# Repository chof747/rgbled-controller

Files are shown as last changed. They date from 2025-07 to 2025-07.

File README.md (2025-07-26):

# RGB-Led Controller

## Idea

This is a WiFi enabled RGB LED controller with the following features:

- Power in from the main 5V power source and stepping down to 3v3 for the MCU
- Pass through of the power to the led strips
- ESP8266 MCU with boot strap, reset and flash logic
- Programming header for auto-reset and flash enabled programming
- Boot and reset button
- IDC header breaking out I2C, 3v3, GND, FLASH (as additional GPIO) and RESET pin
- LED data out (at level of 5V via level shifter)
- Breakout of not used GPIOs 12-14 plus GND
- Wake up circuit prepared with a solder bridge

The WiFi controller is also ammended by a peripheral board that contains:

- 5 Light and 1 Mod Button
- A Temperature and Humidity Sensor
- An MCP23017 for IO expansion
- A breakout for the unused pins of the IO Expander
- An IDC connection with the same pin-out as the IDC connection of the Controller

## Components

- ESP8266 as an ESP12-F module
- ME6211C33M5G-N (voltage regulator)
- 2n7002 MOSFET (level shifting)
- UMH3N (auto reset circuit)
- Screw terminals for Power in and LED Power + Control out
- IDC 2x3 for I2C breakout
- Std Pin headers for programming header and unused pins breakout
- 0.5A Fuse
- SMD Push buttons
- MCP23017 (I2C)
- SHT40x (temperature controller)
- BAT54C (OR Gate type diodes)

## Revision History

**V1.0** - send to production 26.07.2025

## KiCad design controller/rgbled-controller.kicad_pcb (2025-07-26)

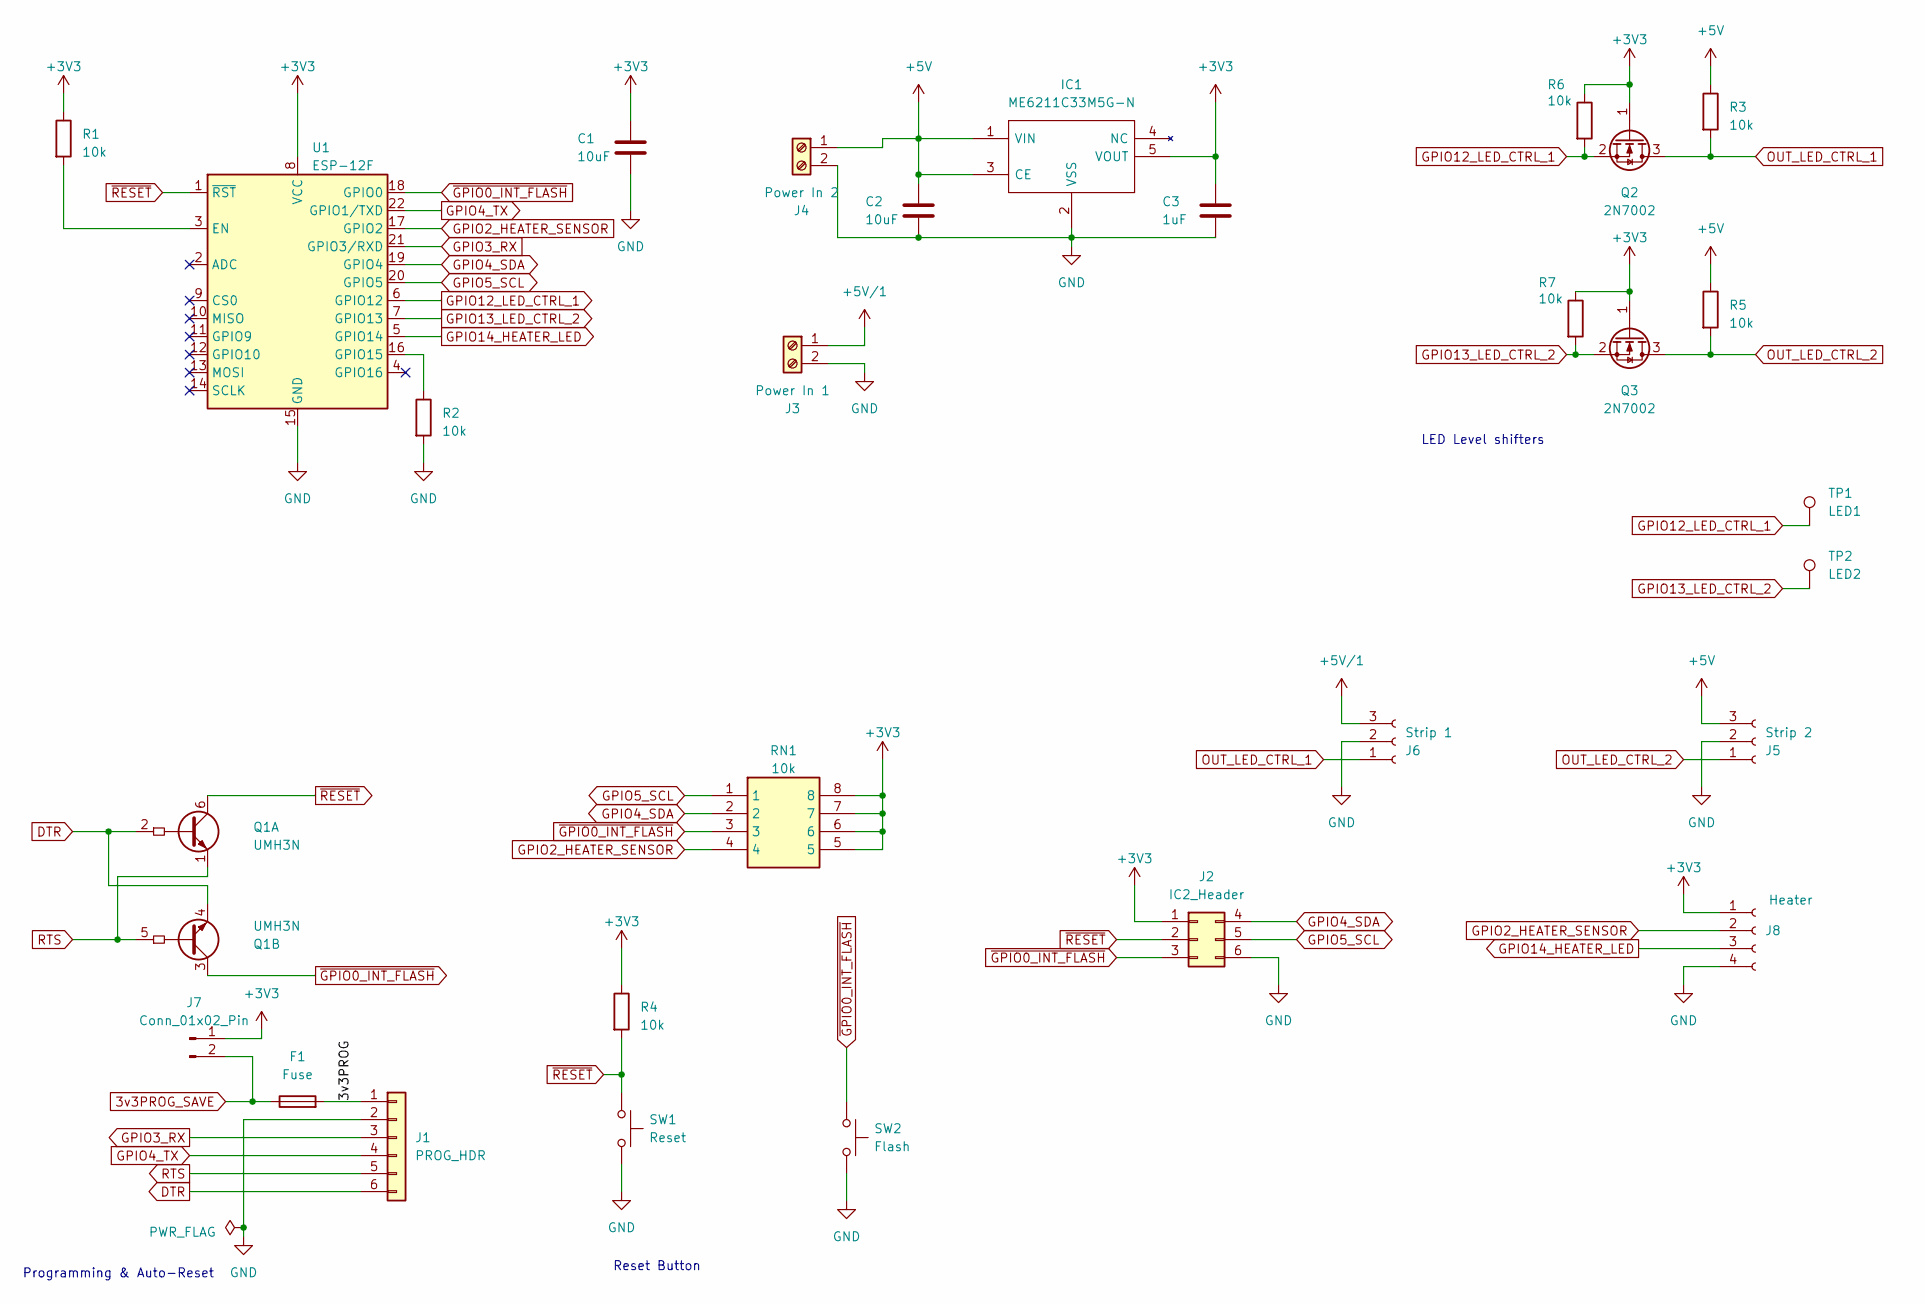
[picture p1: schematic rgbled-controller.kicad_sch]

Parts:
C1, C2: 10uF; C_0603_1608Metric_Pad1.08x0.95mm_HandSolder
C3: 1uF; C_0603_1608Metric_Pad1.08x0.95mm_HandSolder
F1: Fuse; Fuse_0805_2012Metric_Pad1.15x1.40mm_HandSolder
IC1: ME6211C33M5G-N; SOT95P270X145-5N; Manufacturer_Part_Number ME6211C33M5G-N
J1: PROG_HDR; PinHeader_1x06_P2.54mm_Vertical
J2: IC2_Header; HDR-TH_6P-P2.54-V-F-R2-C3-S2.54-4
J3: Power In 1; TerminalBlock_bornier-2_P5.08mm
J4: Power In 2; TerminalBlock_bornier-2_P5.08mm
J5: Strip 2; TerminalBlock_bornier-3_P5.08mm
J6: Strip 1; TerminalBlock_bornier-3_P5.08mm
J7: Conn_01x02_Pin; PinHeader_1x02_P2.54mm_Vertical
J8: Heater; CONN-TH_4P-P2.54_KF128-2.54-4P
Q1: UMH3N; SOT-363_SC-70-6
Q2, Q3: 2N7002; SOT-23
R1, R2, R3, R4, R5, R6, R7: 10k; R_0603_1608Metric_Pad0.98x0.95mm_HandSolder
RN1: 10k; YC164JR07220RL; Manufacturer_Part_Number YC164-FR-0710KL; Mouser Part Number 603-YC164-FR-0710KL
SW1: Reset; KEY-SMD_L3.9-W3.0-LS5.0-EH
SW2: Flash; KEY-SMD_L3.9-W3.0-LS5.0-EH
TP1: LED1; TestPoint_Pad_2.0x2.0mm
TP2: LED2; TestPoint_Pad_2.0x2.0mm
U1: ESP-12F; ESP-12E

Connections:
3v3PROG_SAVE: F1.1, J7.2
+3V3: C1.1, C3.1, IC1.5 (VOUT), J2.1, J7.1, J8.1, Q2.1 (G), Q3.1 (G), R1.1, R4.1, R6.1, R7.1, RN1.5, RN1.6, RN1.7, RN1.8, U1.8 (VCC)
+5V: C2.1, IC1.1 (VIN), IC1.3 (CE), J4.1, J5.3, R3.1, R5.1
+5V/1: J3.1, J6.3
/3v3PROG: F1.2, J1.1
DTR: J1.6, Q1.2 (B1), Q1.4 (E2)
GND: C1.2, C2.2, C3.2, IC1.2 (VSS), J1.2, J2.6, J3.2, J4.2, J5.2, J6.2, J8.4, R2.2, SW1.2, SW2.2, U1.15 (GND)
GPIO2_HEATER_SENSOR: J8.2, RN1.4, U1.17 (GPIO2)
GPIO3_RX: J1.3, U1.21 (GPIO3/RXD)
GPIO4_SDA: J2.4, RN1.2, U1.19 (GPIO4)
GPIO4_TX: J1.4, U1.22 (GPIO1/TXD)
GPIO5_SCL: J2.5, RN1.1, U1.20 (GPIO5)
GPIO12_LED_CTRL_1: Q2.2 (S), R6.2, TP1.1, U1.6 (GPIO12)
GPIO13_LED_CTRL_2: Q3.2 (S), R7.2, TP2.1, U1.7 (GPIO13)
GPIO14_HEATER_LED: J8.3, U1.5 (GPIO14)
unnamed: R1.2, U1.3 (EN)
unnamed: R2.1, U1.16 (GPIO15)
OUT_LED_CTRL_1: J6.1, Q2.3 (D), R3.2
OUT_LED_CTRL_2: J5.1, Q3.3 (D), R5.2
RTS: J1.5, Q1.1 (E1), Q1.5 (B2)
~GPIO0_INT_FLASH: J2.3, Q1.3 (C2), RN1.3, SW2.1, U1.18 (GPIO0)
~RESET: J2.2, Q1.6 (C1), R4.2, SW1.1, U1.1 (~RST)

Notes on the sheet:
Programming & Auto-Reset
Reset Button
LED Level shifters

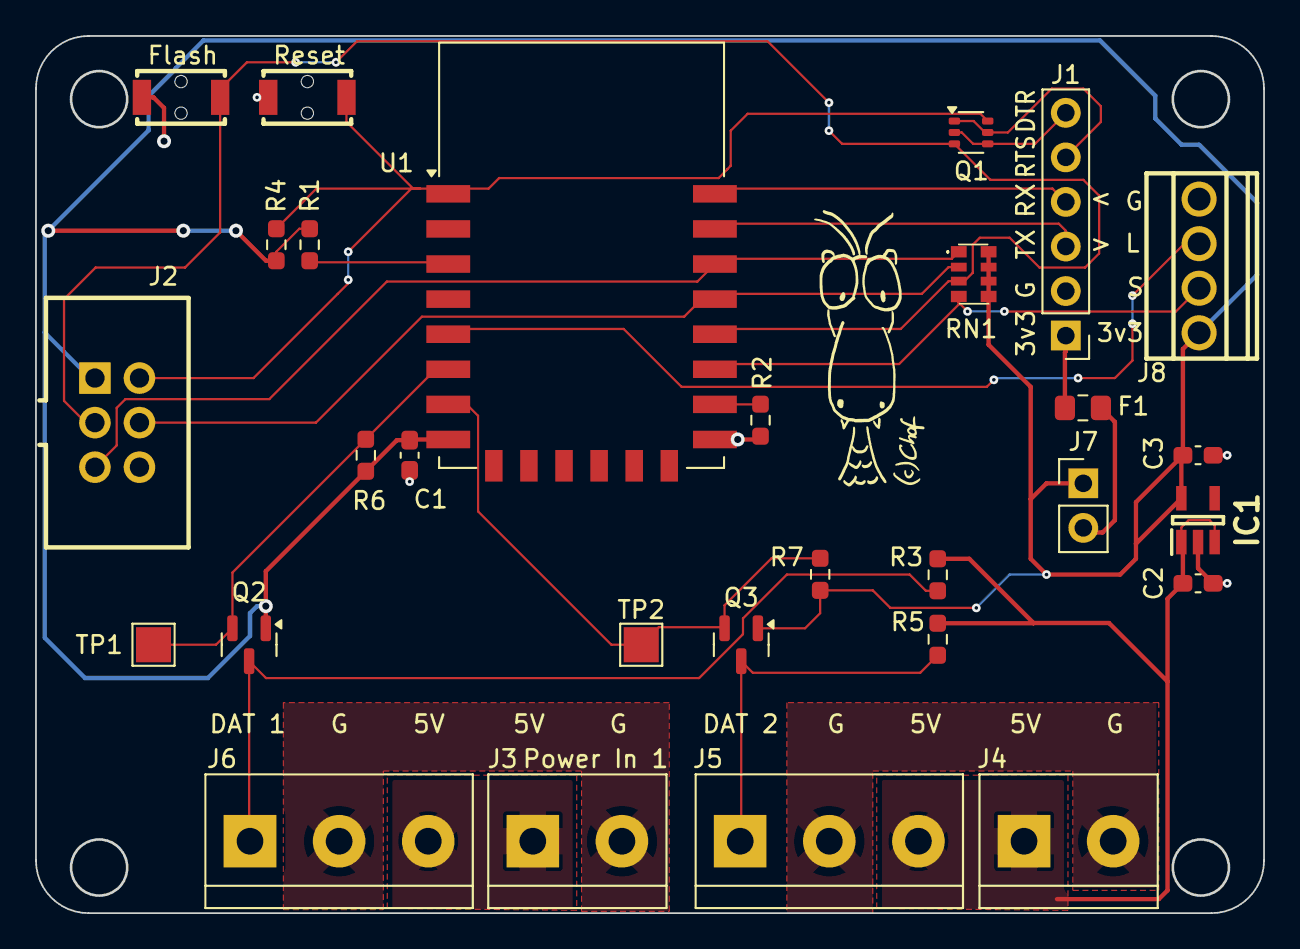
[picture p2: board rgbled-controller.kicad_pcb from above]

Board: 2 copper layers, 70.0 x 50.0 mm, 29 parts (0 on the bottom side), 22 nets.

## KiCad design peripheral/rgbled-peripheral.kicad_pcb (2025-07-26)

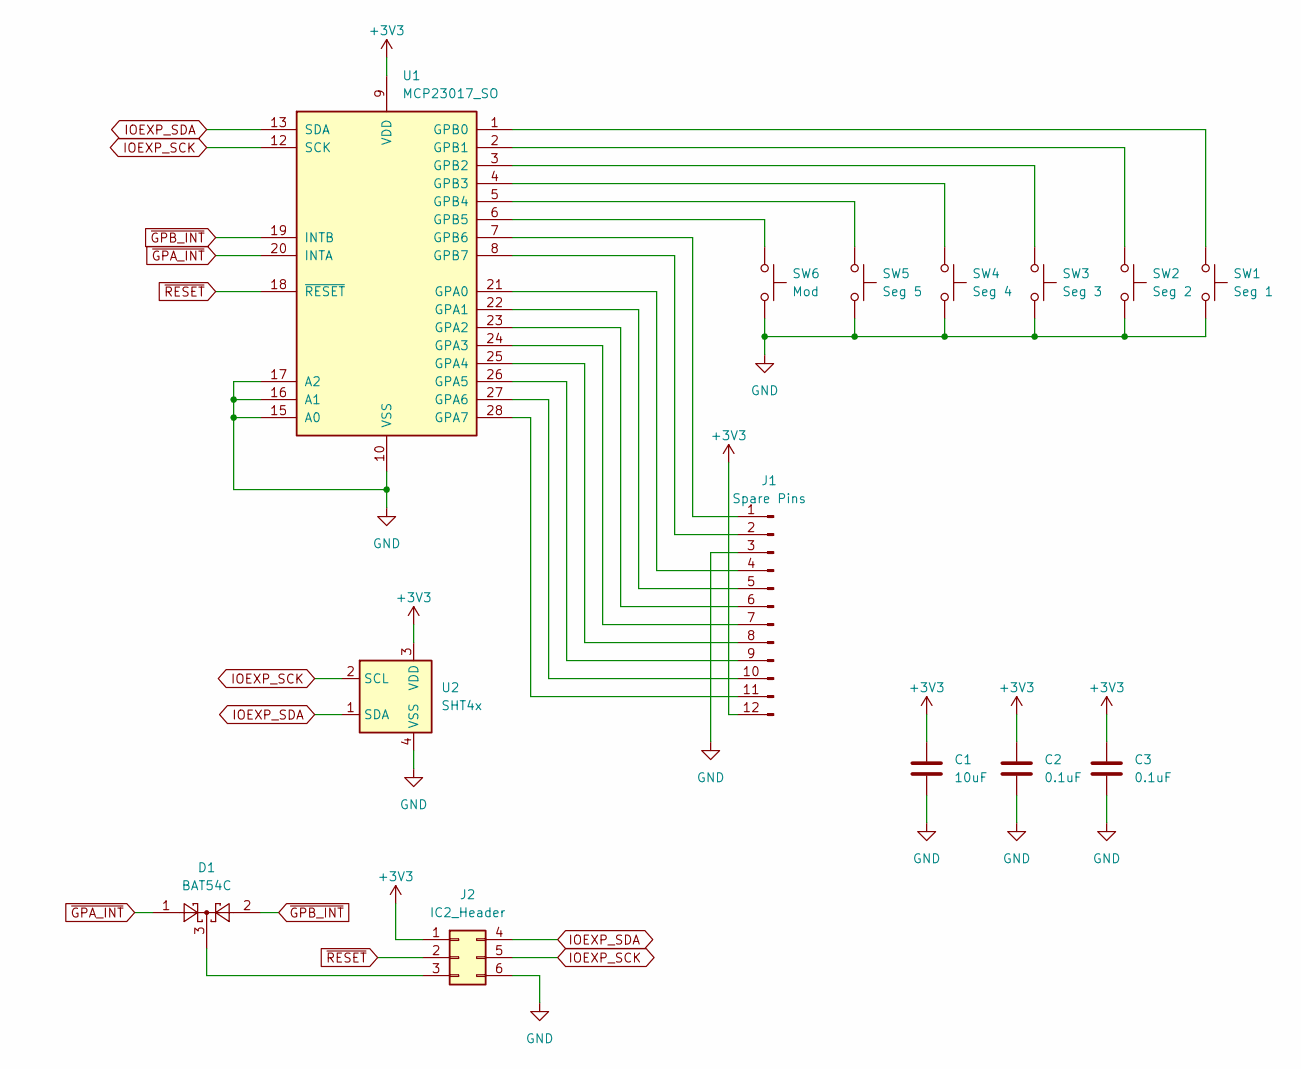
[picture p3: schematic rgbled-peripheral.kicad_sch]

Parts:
C1: 10uF; C_0603_1608Metric_Pad1.08x0.95mm_HandSolder
C2, C3: 0.1uF; C_0603_1608Metric_Pad1.08x0.95mm_HandSolder
D1: BAT54C; SOT-23
J1: Spare Pins; PinHeader_1x12_P2.54mm_Vertical
J2: IC2_Header; HDR-TH_6P-P2.54-V-F-R2-C3-S2.54-4
SW1: Seg 1; KEY-SMD_L3.9-W3.0-LS5.0-EH
SW2: Seg 2; KEY-SMD_L3.9-W3.0-LS5.0-EH
SW3: Seg 3; KEY-SMD_L3.9-W3.0-LS5.0-EH
SW4: Seg 4; KEY-SMD_L3.9-W3.0-LS5.0-EH
SW5: Seg 5; KEY-SMD_L3.9-W3.0-LS5.0-EH
SW6: Mod; KEY-SMD_L3.9-W3.0-LS5.0-EH
U1: MCP23017_SO; SOIC-28W_7.5x17.9mm_P1.27mm
U2: SHT4x; Sensirion_DFN-4_1.5x1.5mm_P0.8mm_SHT4x_NoCentralPad

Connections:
+3V3: C1.1, C2.1, C3.1, J1.12, J2.1, U1.9 (VDD), U2.3 (VDD)
GND: C1.2, C2.2, C3.2, J1.3, J2.6, SW1.2, SW2.2, SW3.2, SW4.2, SW5.2, SW6.2, U1.10 (VSS), U1.15 (A0), U1.16 (A1), U1.17 (A2), U2.4 (VSS)
IOEXP_SCK: J2.5, U1.12 (SCK), U2.2 (SCL)
IOEXP_SDA: J2.4, U1.13 (SDA), U2.1 (SDA)
unnamed: J1.1, U1.7 (GPB6)
unnamed: J1.2, U1.8 (GPB7)
unnamed: J1.4, U1.21 (GPA0)
unnamed: J1.5, U1.22 (GPA1)
unnamed: J1.6, U1.23 (GPA2)
unnamed: J1.7, U1.24 (GPA3)
unnamed: J1.8, U1.25 (GPA4)
unnamed: J1.9, U1.26 (GPA5)
unnamed: J1.10, U1.27 (GPA6)
unnamed: J1.11, U1.28 (GPA7)
unnamed: D1.3, J2.3
unnamed: SW1.1, U1.1 (GPB0)
unnamed: SW2.1, U1.2 (GPB1)
unnamed: SW3.1, U1.3 (GPB2)
unnamed: SW4.1, U1.4 (GPB3)
unnamed: SW5.1, U1.5 (GPB4)
unnamed: SW6.1, U1.6 (GPB5)
~GPA_INT: D1.1, U1.20 (INTA)
~GPB_INT: D1.2, U1.19 (INTB)
~RESET: J2.2, U1.18 (~RESET)

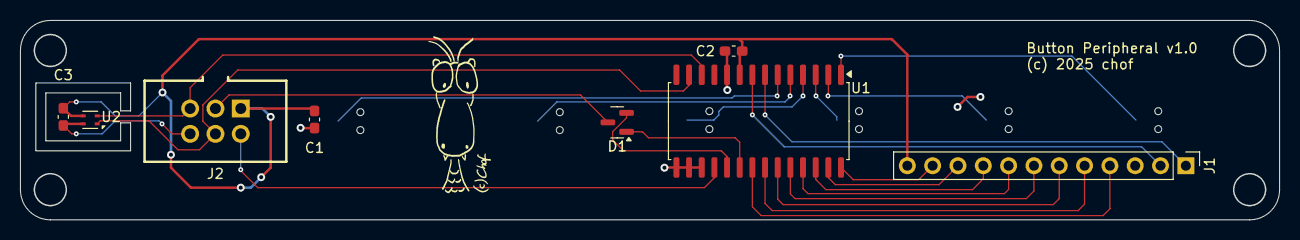
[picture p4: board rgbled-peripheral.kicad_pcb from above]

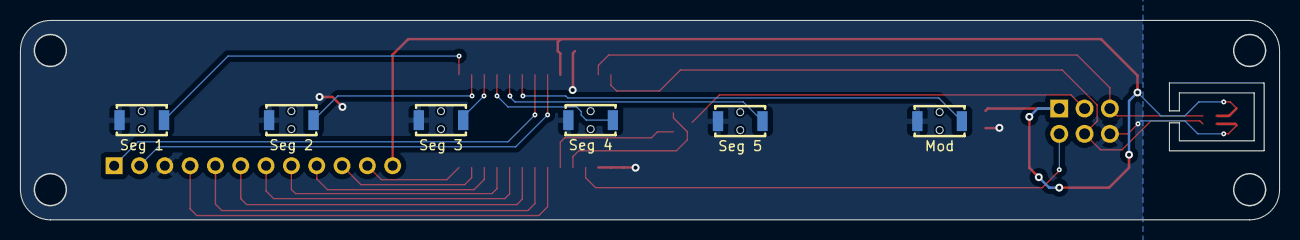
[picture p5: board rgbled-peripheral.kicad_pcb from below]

Board: 2 copper layers, 126.3 x 20.0 mm, 14 parts (6 on the bottom side), 24 nets.

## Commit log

2025-06-30 first version of rgbled controller - no crc check done yet
    [rgbled-controller.kicad_pcb, rgbled-controller.kicad_sch, template-project.kicad_pcb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]
2025-07-01 added 3 mounting points and crc check complete
    [rgbled-controller.kicad_pcb]
2025-07-02 changed board layout and added spare pins
    [rgbled-controller.kicad_pcb, rgbled-controller.kicad_sch]
2025-07-16 Finalized first version of controller board and moved it into controller subdirectory
    [rgbled-controller.kicad_pcb, rgbled-controller.kicad_sch]
2025-07-18 added peripheral board and updated README
    [rgbled-peripheral.kicad_pcb, rgbled-peripheral.kicad_sch]
2025-07-26 initial production version
    [rgbled-controller.kicad_pcb, rgbled-controller.kicad_sch, rgbled-peripheral.kicad_pcb]

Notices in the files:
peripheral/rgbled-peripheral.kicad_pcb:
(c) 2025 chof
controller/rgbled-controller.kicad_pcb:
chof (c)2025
